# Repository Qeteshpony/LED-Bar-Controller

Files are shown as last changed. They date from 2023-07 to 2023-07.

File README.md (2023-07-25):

# Qeteshs 2-Color LED Bar Controller



3D Render

[Hardware Documentation](https://qeteshpony.github.io/LED-Bar-Controller)

This controller replaces the cable bound remote control for a 2-Color USB LED bar and includes an ESP32-WROOM-32 for connecting it to home automation

The board also features a USB-C port for power, a 3-Pin PH2.0 plug for connecting the LED bar and four buttons to control power, brightness and light-temperature. 

All parts on the top side are selected from the JLCPCB basic library for cheap production. The ESP module and the connectors need manual soldering on the bottom side unless two-sided pcb assembly is used.

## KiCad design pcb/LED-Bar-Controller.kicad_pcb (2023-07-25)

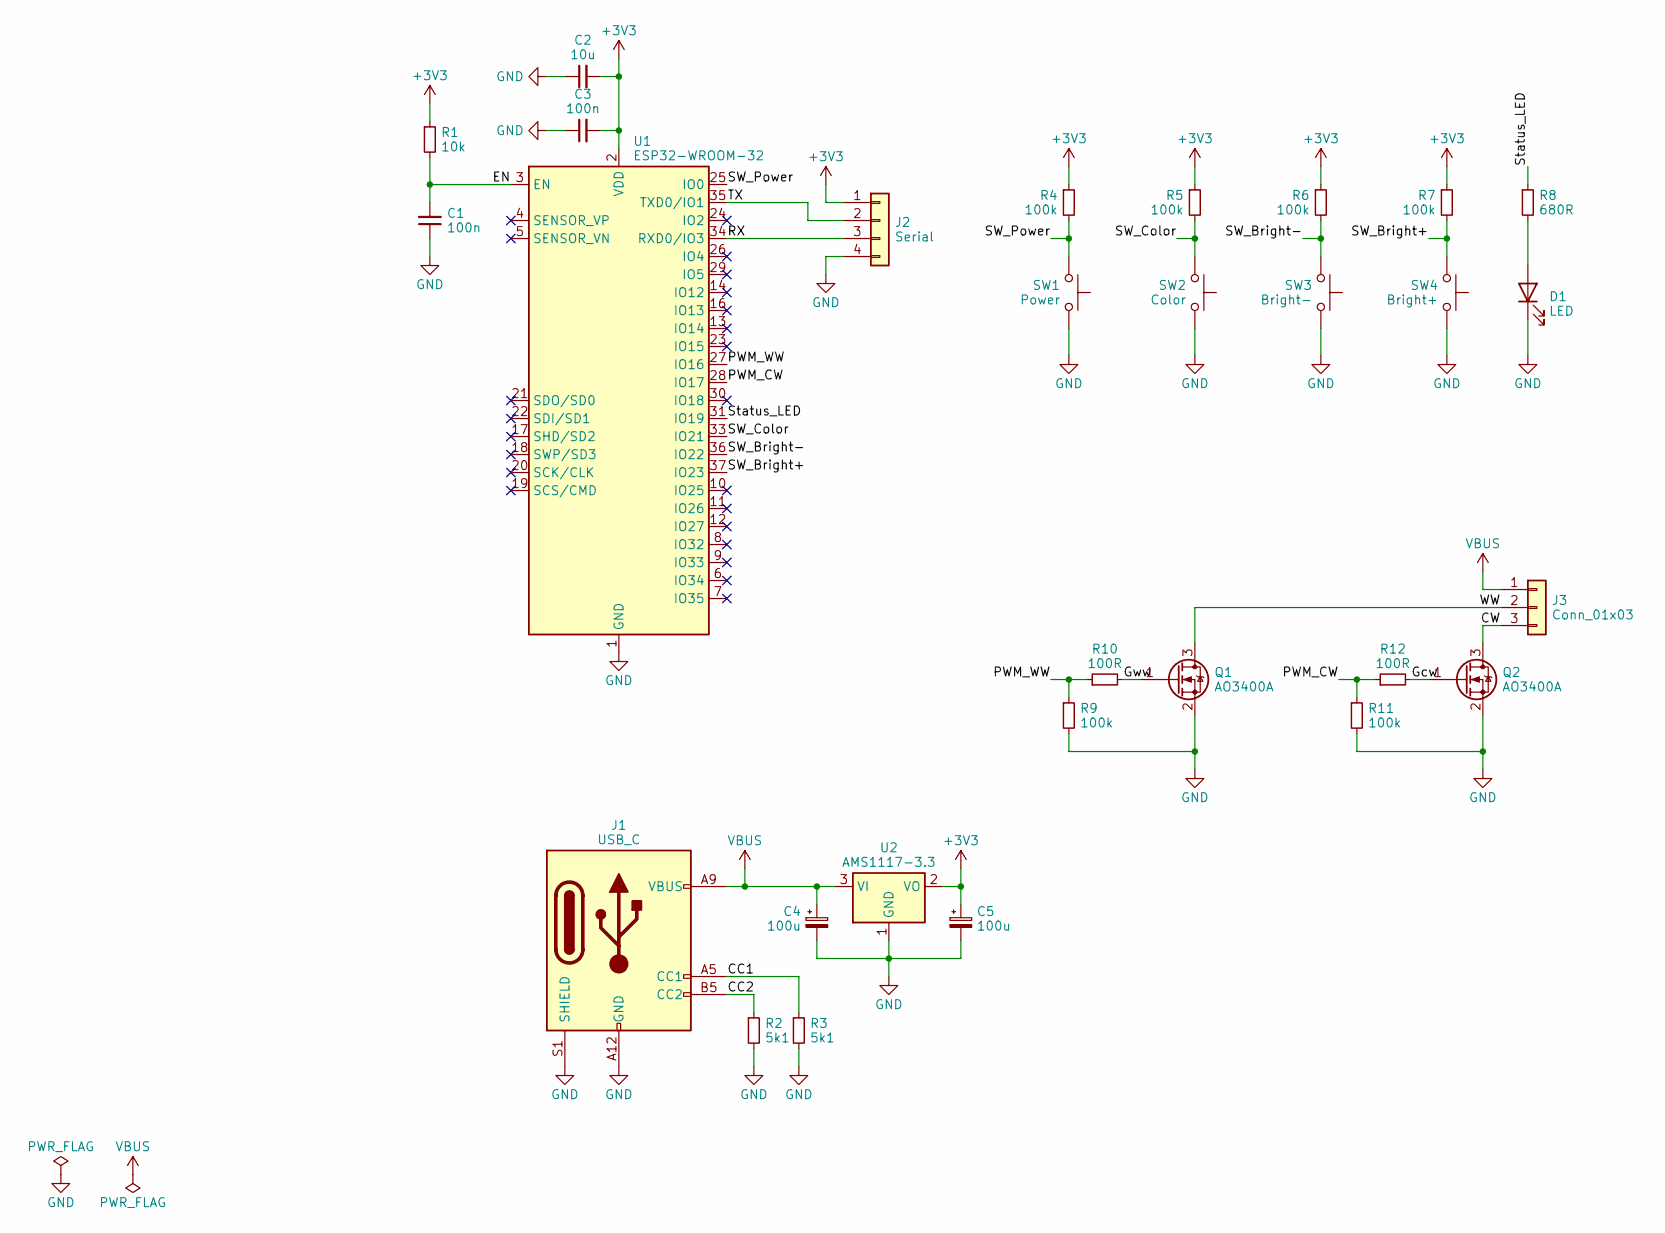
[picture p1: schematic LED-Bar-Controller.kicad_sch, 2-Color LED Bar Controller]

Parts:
C1, C3: 100n; C_0402_1005Metric; LCSC C1525
C2: 10u; C_0402_1005Metric; LCSC C15525
C4, C5: 100u; CP_EIA-3528-21_Kemet-B; LCSC C16133
D1: LED; LED_0603_1608Metric; LCSC C2286
J1: USB_C; GCT_USB4125-GF-A_REVA2
J2: Serial; PinSocket_1x04_P2.54mm_Vertical
J3: Conn_01x03; JST_PH_S3B-PH-K_1x03_P2.00mm_Horizontal
Q1, Q2: AO3400A; SOT-23; LCSC C20917
R1: 10k; R_0402_1005Metric; LCSC C25744
R2, R3: 5k1; R_0402_1005Metric; LCSC C25905
R4, R5, R6, R7, R9, R11: 100k; R_0402_1005Metric; LCSC C25741
R8: 680R; R_0603_1608Metric; LCSC C23228
R10, R12: 100R; R_0402_1005Metric; LCSC C25076
SW1: Power; SW_Push_1P1T_XKB_TS-1187A; LCSC C318884
SW2: Color; SW_Push_1P1T_XKB_TS-1187A; LCSC C318884
SW3: Bright-; SW_Push_1P1T_XKB_TS-1187A; LCSC C318884
SW4: Bright+; SW_Push_1P1T_XKB_TS-1187A; LCSC C318884
U1: ESP32-WROOM-32
U2: AMS1117-3.3; SOT-223-3_TabPin2; LCSC C6186

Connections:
+3V3: C2.2, C3.2, C5.1, J2.1, R1.1, R4.1, R5.1, R6.1, R7.1, U1.2 (VDD), U2.2 (VO)
/CC1: J1.A5 (CC1), R3.1
/CC2: J1.B5 (CC2), R2.1
/CW: J3.3, Q2.3 (D)
/EN: C1.2, R1.2, U1.3 (EN)
/Gcw: Q2.1 (G), R12.2
/Gww: Q1.1 (G), R10.2
/PWM_CW: R11.1, R12.1, U1.28 (IO17)
/PWM_WW: R9.1, R10.1, U1.27 (IO16)
/RX: J2.3, U1.34 (RXD0/IO3)
/SW_Bright+: R7.2, SW4.2, U1.37 (IO23)
/SW_Bright-: R6.2, SW3.2, U1.36 (IO22)
/SW_Color: R5.2, SW2.2, U1.33 (IO21)
/SW_Power: R4.2, SW1.2, U1.25 (IO0)
/Status_LED: R8.1, U1.31 (IO19)
/TX: J2.2, U1.35 (TXD0/IO1)
/WW: J3.2, Q1.3 (D)
GND: C1.1, C2.1, C3.1, C4.2, C5.2, D1.1 (K), J1.A12 (GND), J1.B12 (GND), J1.S1 (SHIELD), J2.4, Q1.2 (S), Q2.2 (S), R2.2, R3.2, R9.2, R11.2, SW1.1, SW2.1, SW3.1, SW4.1, U1.1 (GND), U1.15 (GND), U1.38 (GND), U1.39 (GND), U2.1 (GND)
unnamed: D1.2 (A), R8.2
VBUS: C4.1, J1.A9 (VBUS), J1.B9 (VBUS), J3.1, U2.3 (VI)

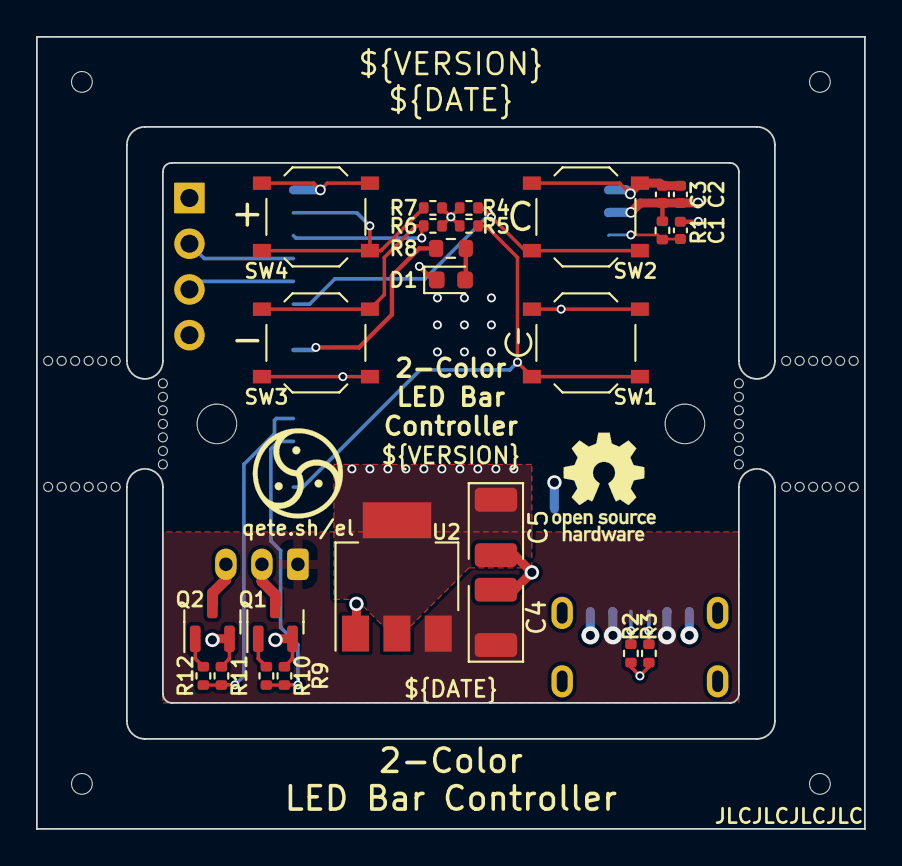
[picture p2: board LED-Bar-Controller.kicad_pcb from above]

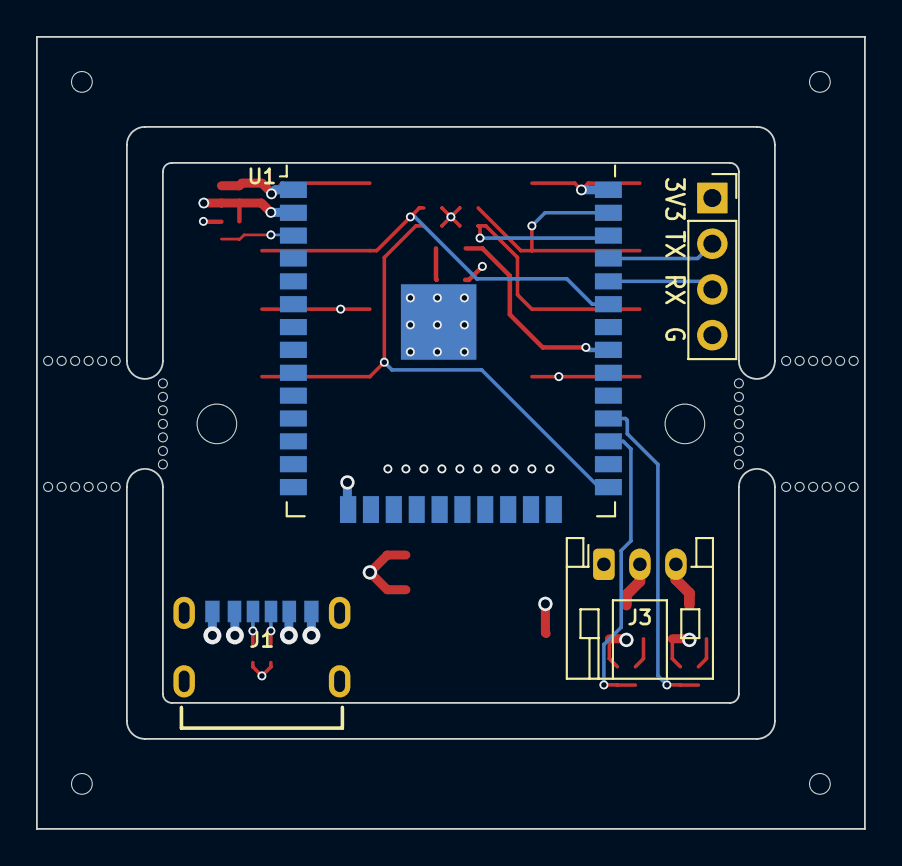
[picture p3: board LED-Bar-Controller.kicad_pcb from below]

Board: 4 copper layers, 46.0 x 44.0 mm, 35 parts (4 on the bottom side), 20 nets.

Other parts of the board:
mouse-bite-2mm-slot, mouse-bite-2mm-slot#3, mouse-bite-2mm-slot#5, mouse-bite-2mm-slot#6: VAL**; mouse-bite-5mm-railbreaker
mouse-bite-2mm-slot#2, mouse-bite-2mm-slot#4: VAL**; mouse-bite-2x5mm-slot-onesided-v2

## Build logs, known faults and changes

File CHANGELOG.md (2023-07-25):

# Changelog

## [1.0.1](https://github.com/Qeteshpony/LED-Bar-Controller/compare/v1.0.0...v1.0.1) (2023-07-25)

### Bug Fixes

* replace too small vias ([ae0ffce](https://github.com/Qeteshpony/LED-Bar-Controller/commit/ae0ffce0f52476345e111085fe67b47356b5a48a))

## 1.0.0 (2023-07-25)

### Features

* add JLC part numbers for all basic parts ([1331acd](https://github.com/Qeteshpony/LED-Bar-Controller/commit/1331acd23e996f76c36e4c64186e84b16203749c))
* add mouse bites ([839a3b9](https://github.com/Qeteshpony/LED-Bar-Controller/commit/839a3b969d89606a4b49fe72e6cd98c4f3125b76))
* add origin point ([236b405](https://github.com/Qeteshpony/LED-Bar-Controller/commit/236b405a1031edb4ee44495833543fa450fcad54))
* change button type ([07a0642](https://github.com/Qeteshpony/LED-Bar-Controller/commit/07a0642c686f55d825774c55dd77a424aa1aa17d))
* initial commit ([5341eeb](https://github.com/Qeteshpony/LED-Bar-Controller/commit/5341eebd66f2240b4318e27639c7f90d32b74136))

### Bug Fixes

* improve VBUS connections ([7abfe7a](https://github.com/Qeteshpony/LED-Bar-Controller/commit/7abfe7aa25006e5537e0fa568a9005d7dca5a793))
* switch WW and CW positions ([30cc59c](https://github.com/Qeteshpony/LED-Bar-Controller/commit/30cc59c1966fe960bdcf3cf3378d45c1557acff9))

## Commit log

2023-07-22 feat: initial commit
    [LED-Bar-Controller.kicad_pcb, LED-Bar-Controller.kicad_sch]
2023-07-22 feat: add JLC part numbers for all basic parts
    [LED-Bar-Controller.kicad_pcb, LED-Bar-Controller.kicad_sch]
2023-07-25 fix: switch WW and CW positions
    [LED-Bar-Controller.kicad_pcb, LED-Bar-Controller.kicad_sch]
2023-07-25 feat: change button type
    change buttons to type in JLCPCB basic library and change their positions
    [LED-Bar-Controller.kicad_pcb, LED-Bar-Controller.kicad_sch]
2023-07-25 fix: improve VBUS connections
    [LED-Bar-Controller.kicad_pcb]
2023-07-25 feat: add mouse bites
    Add more mouse bites to make breaking the rails easier
    [LED-Bar-Controller.kicad_pcb]
2023-07-25 feat: add origin point
    [LED-Bar-Controller.kicad_pcb]
2023-07-25 style: silkscreen cleanup
    Renumber parts and clean up silkscreen positioning
    [LED-Bar-Controller.kicad_pcb, LED-Bar-Controller.kicad_sch]
2023-07-25 fix: replace too small vias
    Used too small vias for normal production with JLCPCB
    [LED-Bar-Controller.kicad_pcb]
